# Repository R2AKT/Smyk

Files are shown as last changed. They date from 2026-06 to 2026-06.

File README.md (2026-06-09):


License addendum - https://github.com/R2AKT/Smyk/blob/main/Addendum.txt

# Smyk
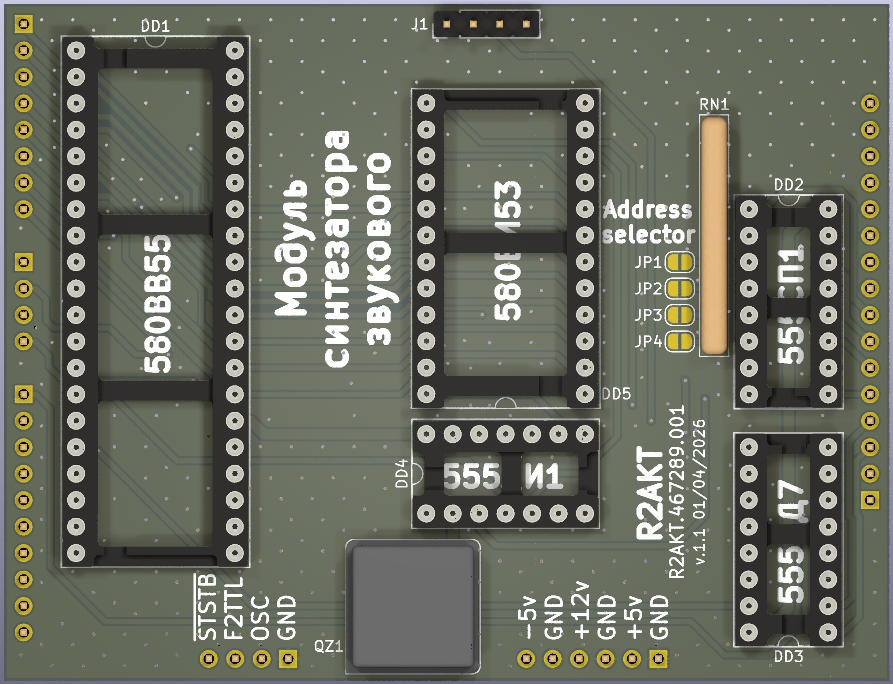
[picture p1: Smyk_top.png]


Sound synthesizer module (Smyk). For Mega-80 (Mega-580) DIY 8-bit micro-computer - https://github.com/R2AKT/Mega-80.

Generation of 3-channel 1-bit sound.

Based on 580VI53 (8253).

Status: In the process of testing.

Модуль синтезатора звукового (Smyk). Для самодельной 8-битной микро-ЭВМ - https://github.com/R2AKT/Mega-80.

Генерация 3-х канального 1-битного звука.

На основе 580ВИ53 (8253).

Статус: В процессе тестирования.

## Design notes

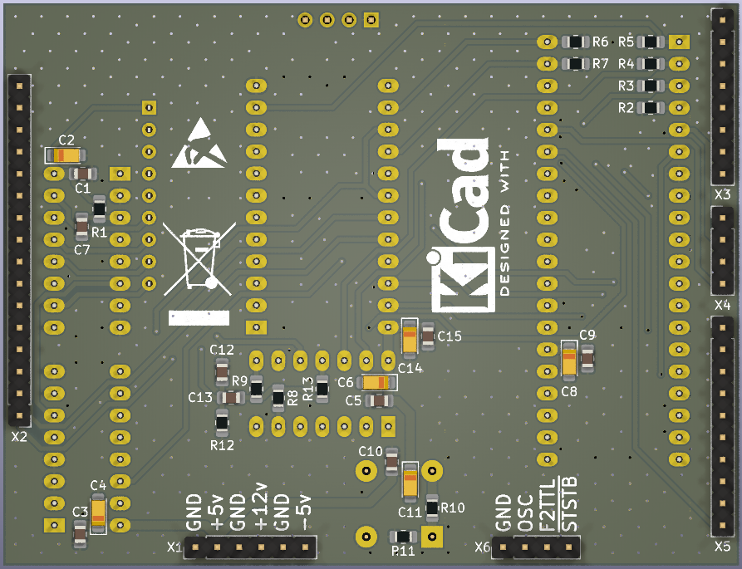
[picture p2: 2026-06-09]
Smyk_btn.png

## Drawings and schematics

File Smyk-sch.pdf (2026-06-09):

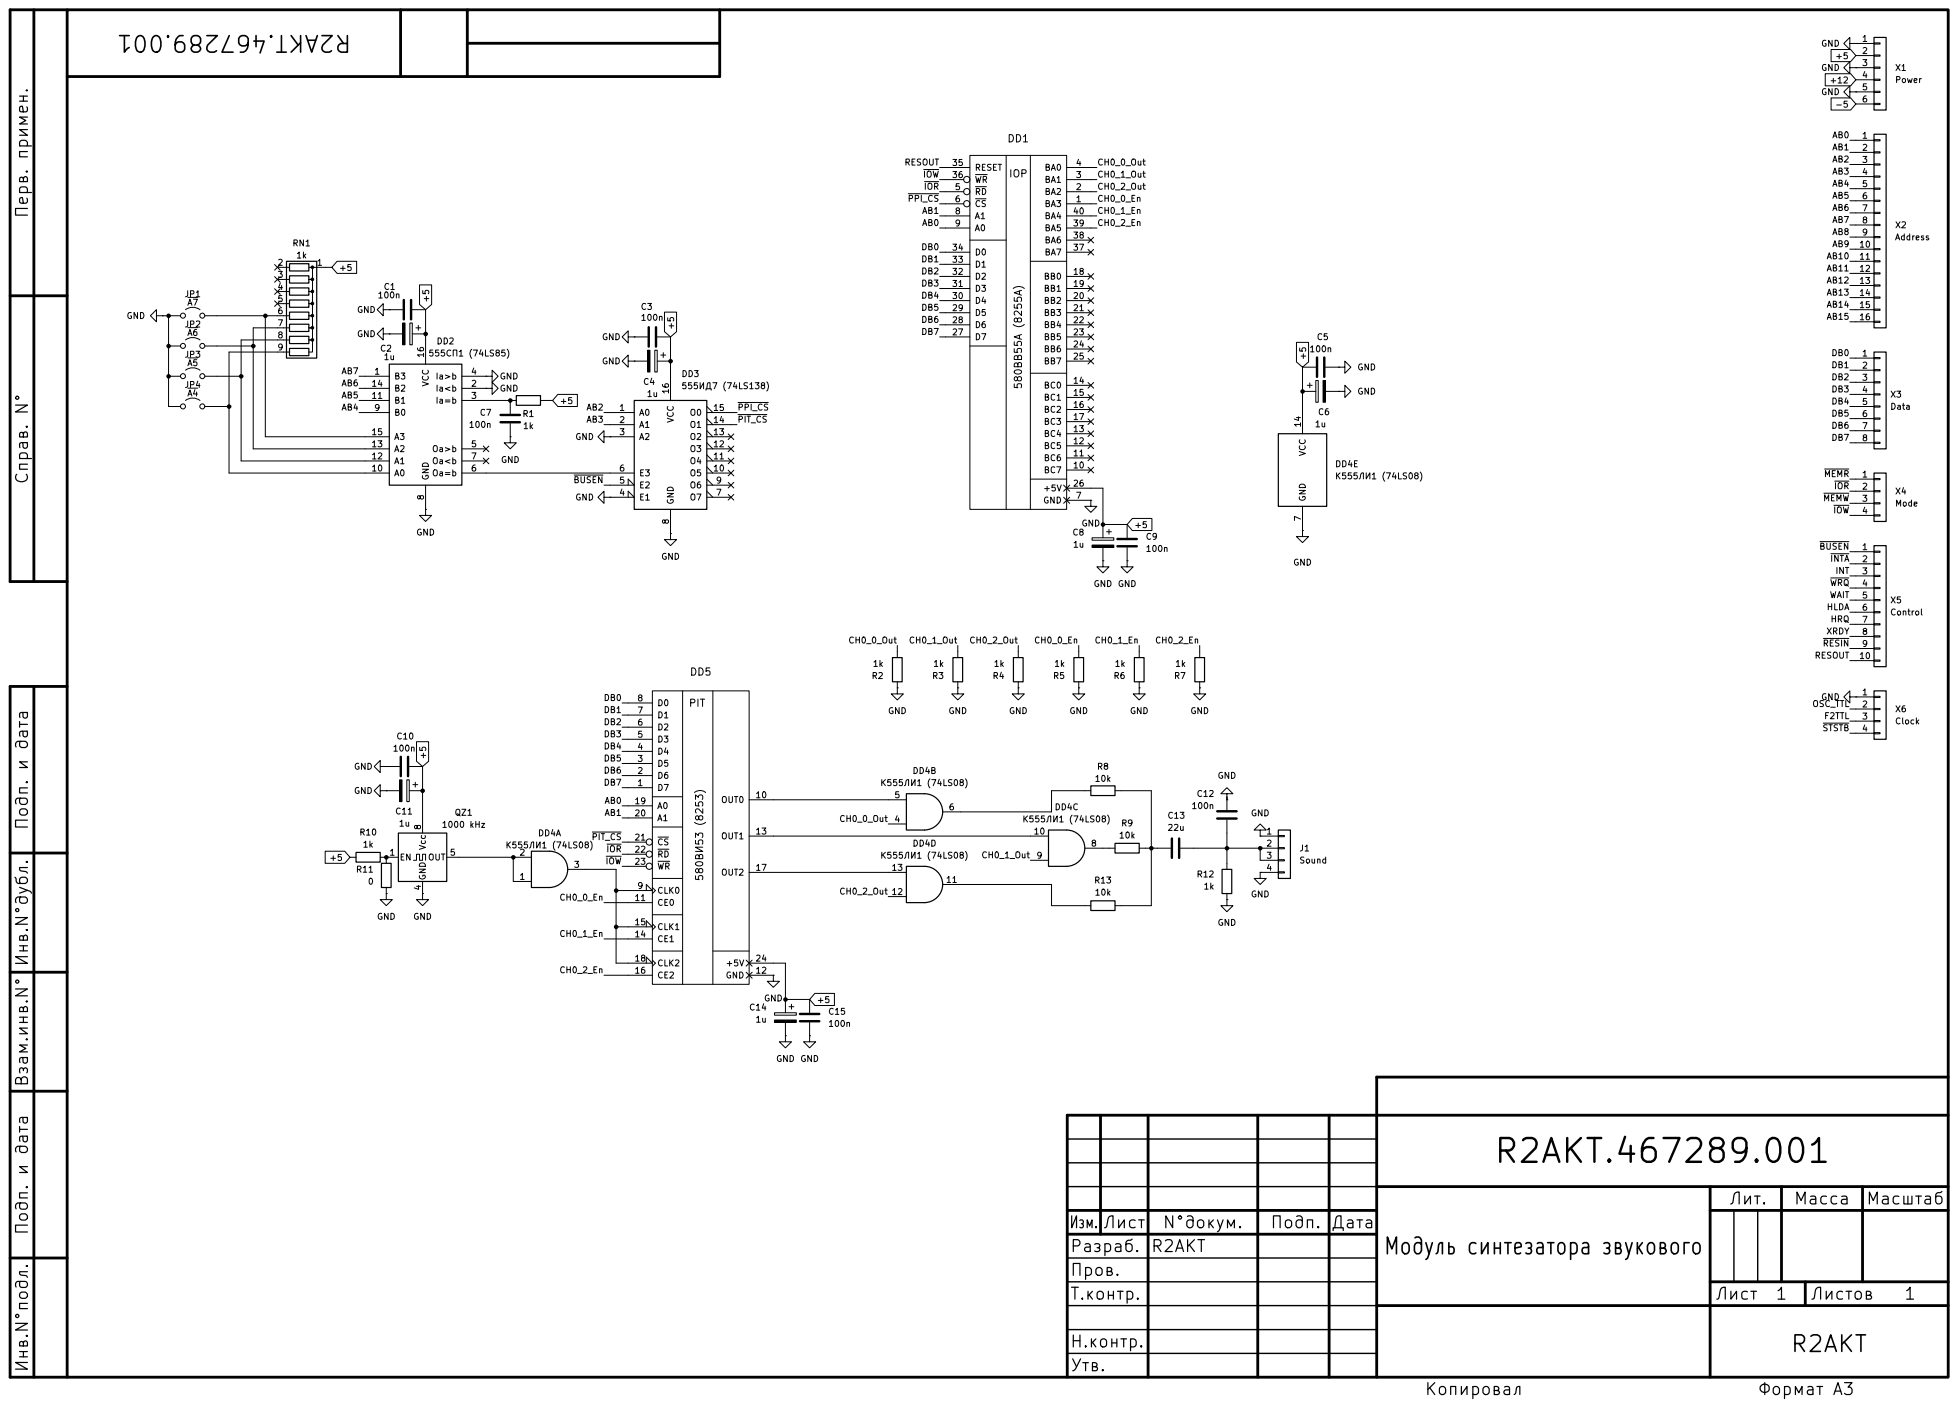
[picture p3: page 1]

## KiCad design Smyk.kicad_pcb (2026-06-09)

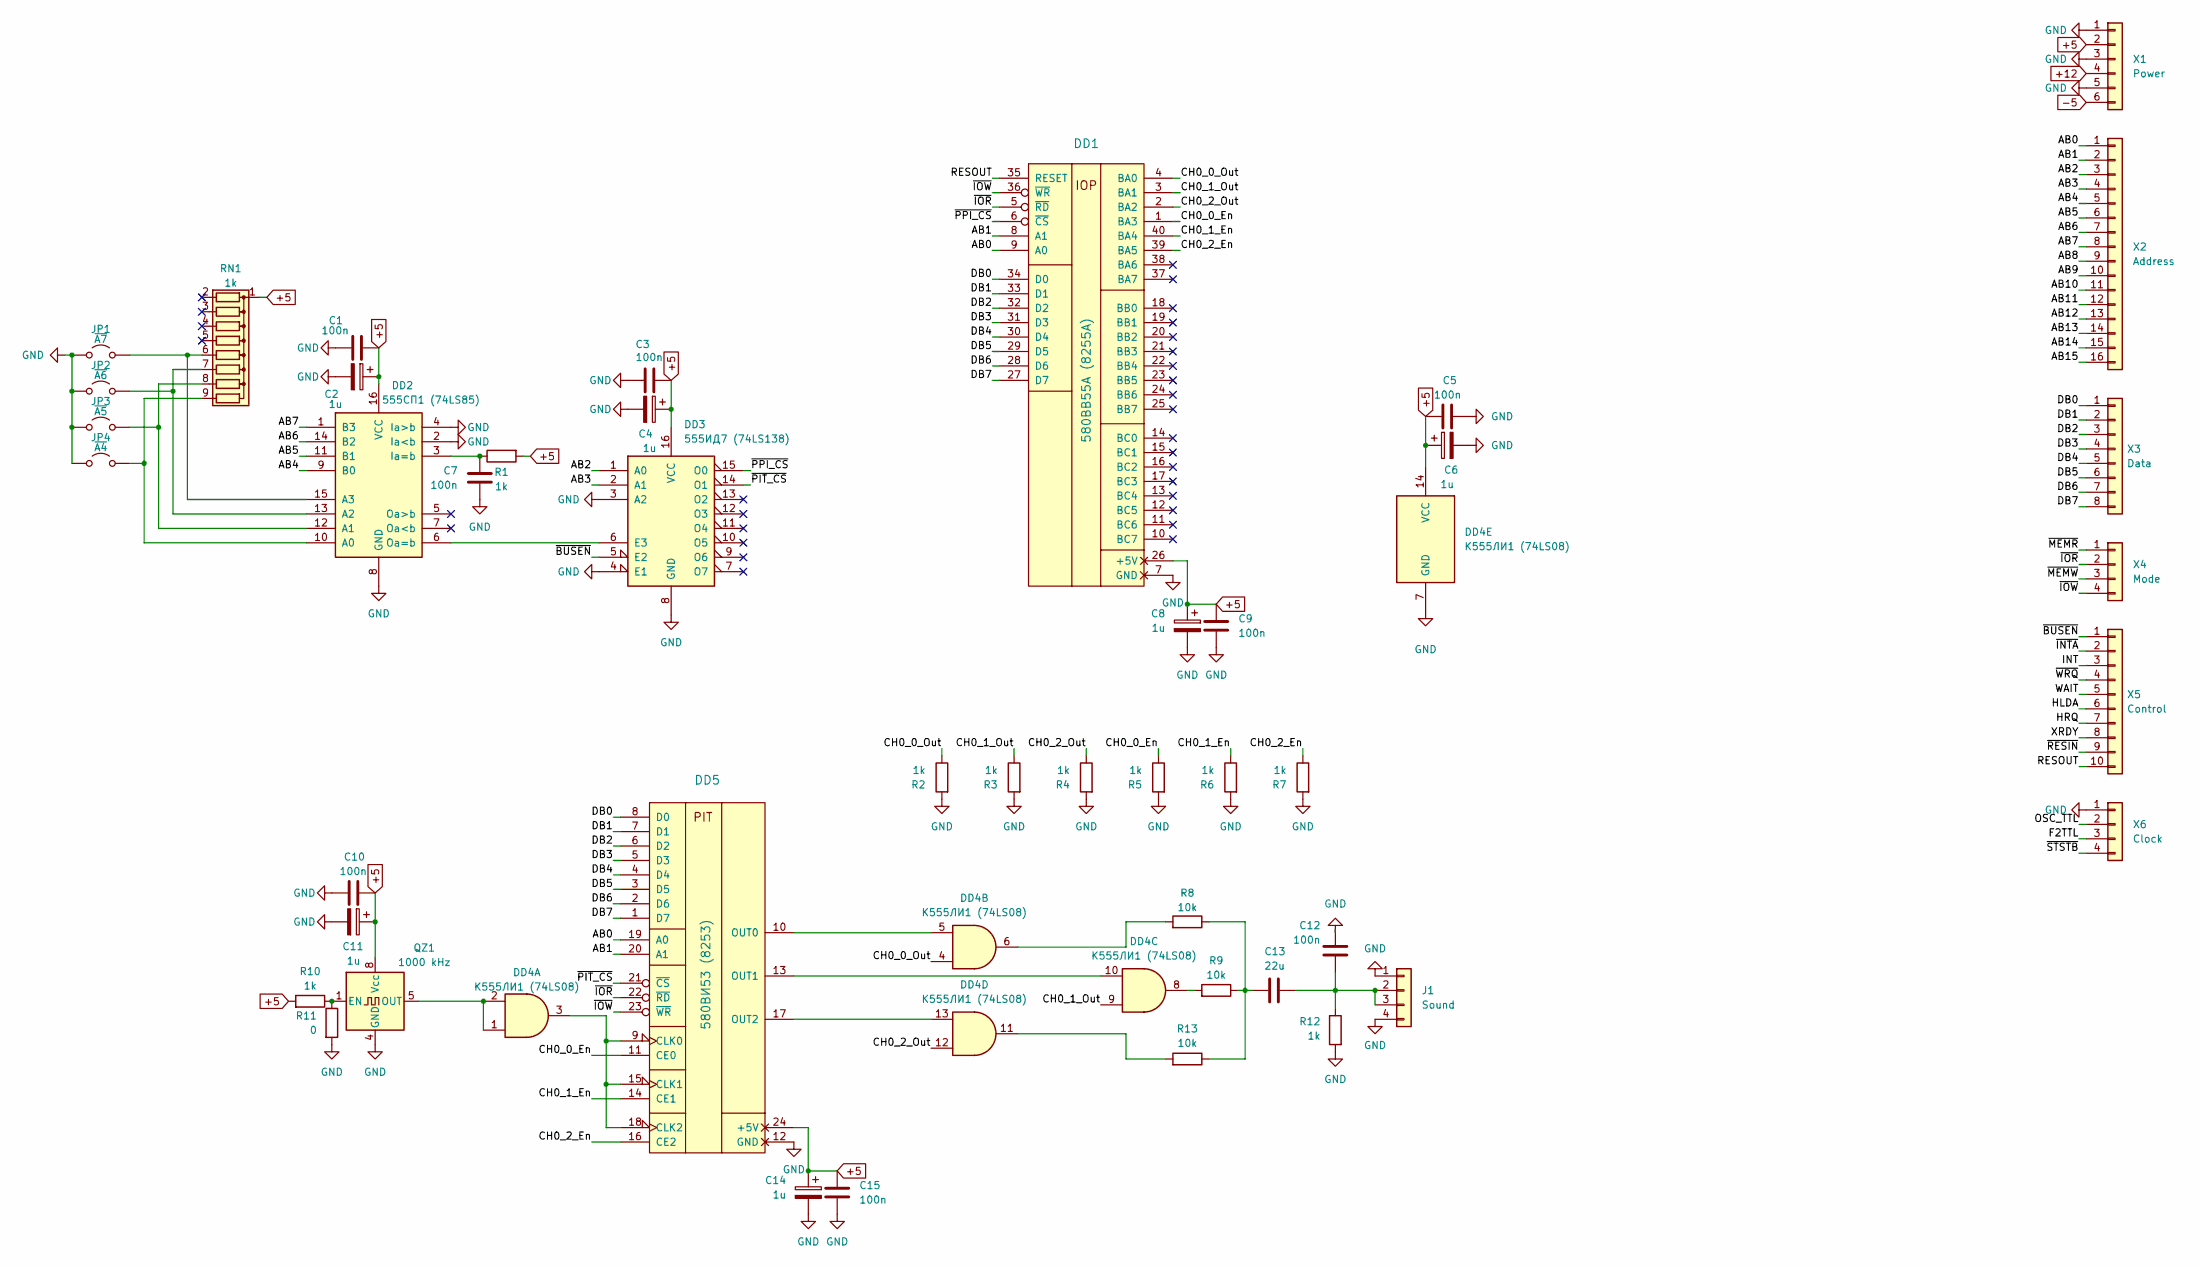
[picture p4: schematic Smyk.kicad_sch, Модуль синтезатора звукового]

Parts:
C1, C3, C5, C7, C9, C10, C12, C15: 100n; C_0805_2012Metric_Pad1.18x1.45mm_HandSolder
C2, C4, C6, C8, C11, C14: 1u; CP_EIA-3216-18_Kemet-A_Pad1.58x1.35mm_HandSolder
C13: 22u; C_0805_2012Metric_Pad1.18x1.45mm_HandSolder
DD1: 580ВВ55A (8255A); DIP-40_W15.24mm_Socket_LongPads
DD2: 555СП1 (74LS85); DIP-16_W7.62mm_Socket_LongPads
DD3: 555ИД7 (74LS138); DIP-16_W7.62mm_Socket_LongPads
DD4: К555ЛИ1 (74LS08); DIP-14_W7.62mm_Socket_LongPads
DD5: 580ВИ53 (8253); DIP-24_W15.24mm_Socket_LongPads
J1: Sound; PinHeader_1x04_P2.54mm_Vertical
JP1: ~{A7}; SolderJumper-2_P1.3mm_Open_RoundedPad1.0x1.5mm
JP2: ~{A6}; SolderJumper-2_P1.3mm_Open_RoundedPad1.0x1.5mm
JP3: ~{A5}; SolderJumper-2_P1.3mm_Open_RoundedPad1.0x1.5mm
JP4: ~{A4}; SolderJumper-2_P1.3mm_Open_RoundedPad1.0x1.5mm
QZ1: 1000 kHz; Oscillator_DIP-8_LargePads
R1, R2, R3, R4, R5, R6, R7, R10, R12: 1k; R_0805_2012Metric_Pad1.20x1.40mm_HandSolder
R8, R9, R13: 10k; R_0805_2012Metric_Pad1.20x1.40mm_HandSolder
R11: 0; R_0805_2012Metric_Pad1.20x1.40mm_HandSolder
RN1: 1k; R_Array_SIP9
X1: Power; PinHeader_1x06_P2.54mm_Vertical
X2: Address; PinHeader_1x16_P2.54mm_Vertical
X3: Data; PinHeader_1x08_P2.54mm_Vertical
X4: Mode; PinHeader_1x04_P2.54mm_Vertical
X5: Control; PinHeader_1x10_P2.54mm_Vertical
X6: Clock; PinHeader_1x04_P2.54mm_Vertical

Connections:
+5: C1.1, C2.1, C3.1, C4.1, C5.1, C6.1, C8.1, C9.1, C10.1, C11.1, C14.1, C15.1, DD1.26 (+5V), DD2.16 (VCC), DD3.16 (VCC), DD4.14 (VCC), DD5.24 (+5V), QZ1.8 (Vcc), R1.2, R10.2, RN1.1 (common), X1.2
+12: X1.4
-5: X1.6
/AB0: DD1.9 (A0), DD5.19 (A0), X2.1
/AB1: DD1.8 (A1), DD5.20 (A1), X2.2
/AB2: DD3.1 (A0), X2.3
/AB3: DD3.2 (A1), X2.4
/AB4: DD2.9 (B0), X2.5
/AB5: DD2.11 (B1), X2.6
/AB6: DD2.14 (B2), X2.7
/AB7: DD2.1 (B3), X2.8
/AB8: X2.9
/AB9: X2.10
/AB10: X2.11
/AB11: X2.12
/AB12: X2.13
/AB13: X2.14
/AB14: X2.15
/AB15: X2.16
/CH0_0_En: DD1.1 (BA3), DD5.11 (CE0), R5.1
/CH0_0_Out: DD1.4 (BA0), DD4.4, R2.1
/CH0_1_En: DD1.40 (BA4), DD5.14 (CE1), R6.1
/CH0_1_Out: DD1.3 (BA1), DD4.9, R3.1
/CH0_2_En: DD1.39 (BA5), DD5.16 (CE2), R7.1
/CH0_2_Out: DD1.2 (BA2), DD4.12, R4.1
/DB0: DD1.34 (D0), DD5.8 (D0), X3.1
/DB1: DD1.33 (D1), DD5.7 (D1), X3.2
/DB2: DD1.32 (D2), DD5.6 (D2), X3.3
/DB3: DD1.31 (D3), DD5.5 (D3), X3.4
/DB4: DD1.30 (D4), DD5.4 (D4), X3.5
/DB5: DD1.29 (D5), DD5.3 (D5), X3.6
/DB6: DD1.28 (D6), DD5.2 (D6), X3.7
/DB7: DD1.27 (D7), DD5.1 (D7), X3.8
/F2TTL: X6.3
/HLDA: X5.6
/HRQ: X5.7
/INT: X5.3
/OSC_TTL: X6.2
/RESOUT: DD1.35 (RESET), X5.10
/WAIT: X5.5
/XRDY: X5.8
/~BUSEN: DD3.5 (E2), X5.1
/~INTA: X5.2
/~IOR: DD1.5 (~RD), DD5.22 (~RD), X4.2
/~IOW: DD1.36 (~WR), DD5.23 (~WR), X4.4
/~MEMR: X4.1
/~MEMW: X4.3
/~PIT_CS: DD3.14 (O1), DD5.21 (~CS)
/~PPI_CS: DD1.6 (~CS), DD3.15 (O0)
/~RESIN: X5.9
/~STSTB: X6.4
/~WRQ: X5.4
GND: C1.2, C2.2, C3.2, C4.2, C5.2, C6.2, C7.2, C8.2, C9.2, C10.2, C11.2, C12.1, C14.2, C15.2, DD1.7 (GND), DD2.2 (Ia<b), DD2.4 (Ia>b), DD2.8 (GND), DD3.3 (A2), DD3.4 (E1), DD3.8 (GND), DD4.7 (GND), DD5.12 (GND), J1.1, J1.4, JP1.1 (A), JP2.1 (A), JP3.1 (A), JP4.1 (A), QZ1.4 (GND), R2.2, R3.2, R4.2, R5.2, R6.2, R7.2, R11.2, R12.2, X1.1, X1.3, X1.5, X6.1
unnamed: C13.2, R8.1, R9.1, R13.1
unnamed: DD2.10 (A0), JP4.2 (B), RN1.9 (R8)
unnamed: DD2.12 (A1), JP3.2 (B), RN1.8 (R7)
unnamed: DD2.13 (A2), JP2.2 (B), RN1.7 (R6)
unnamed: DD2.15 (A3), JP1.2 (B), RN1.6 (R5)
unnamed: C7.1, DD2.3 (Ia=b), R1.1
unnamed: DD2.6 (Oa=b), DD3.6 (E3)
unnamed: DD4.6, R8.2
unnamed: DD4.8, R9.2
unnamed: DD4.11, R13.2
unnamed: DD4.3, DD5.9 (CLK0), DD5.15 (CLK1), DD5.18 (CLK2)
unnamed: DD4.5, DD5.10 (OUT0)
unnamed: DD4.10, DD5.13 (OUT1)
unnamed: DD4.13, DD5.17 (OUT2)
unnamed: C12.2, C13.1, J1.2, J1.3, R12.1
unnamed: QZ1.1 (EN), R10.1, R11.1
unnamed: DD4.1, DD4.2, QZ1.5 (OUT)

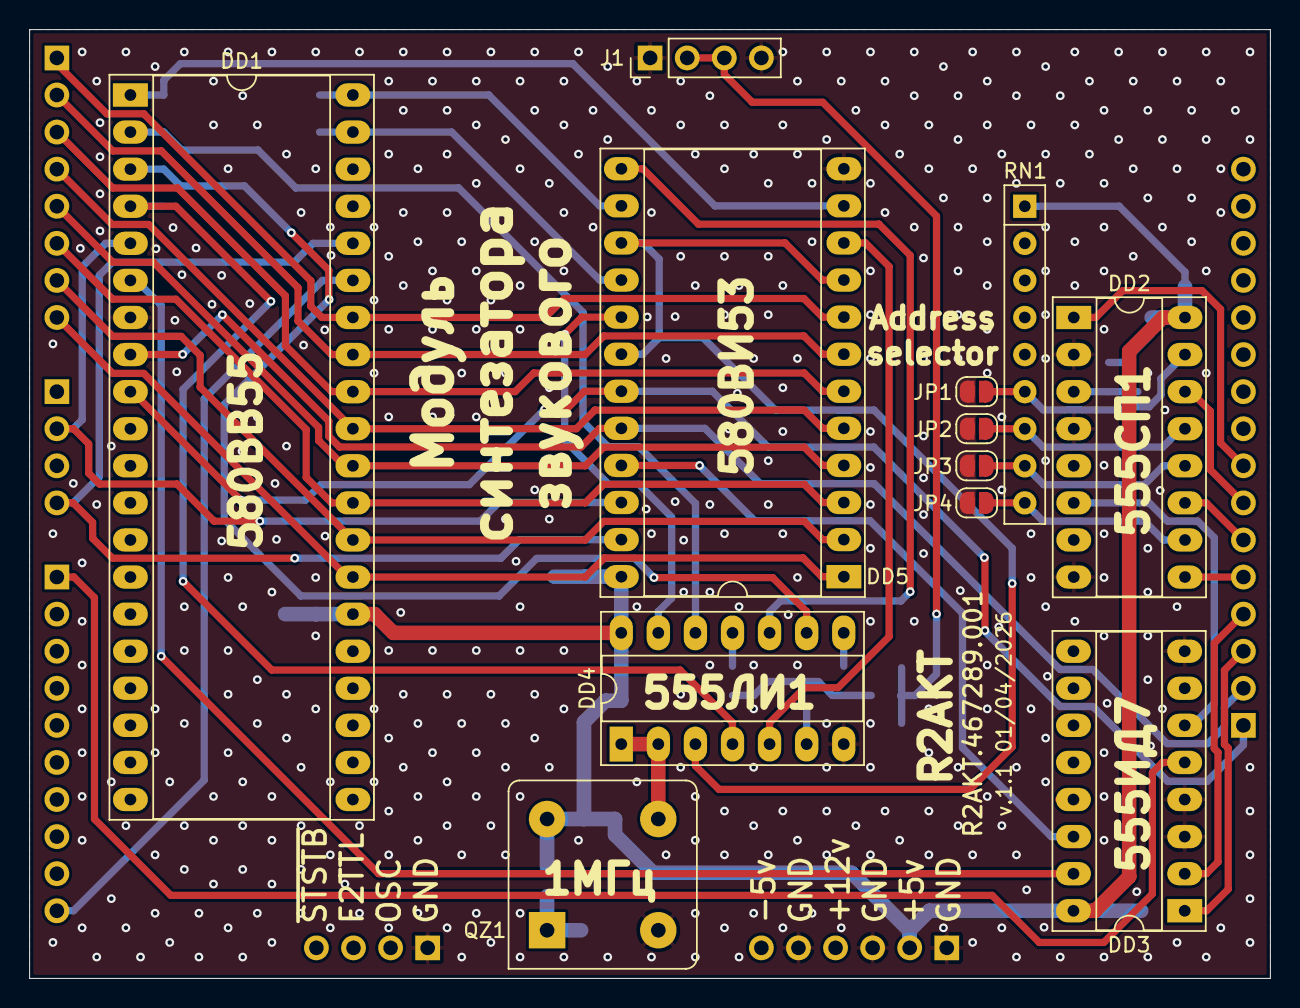
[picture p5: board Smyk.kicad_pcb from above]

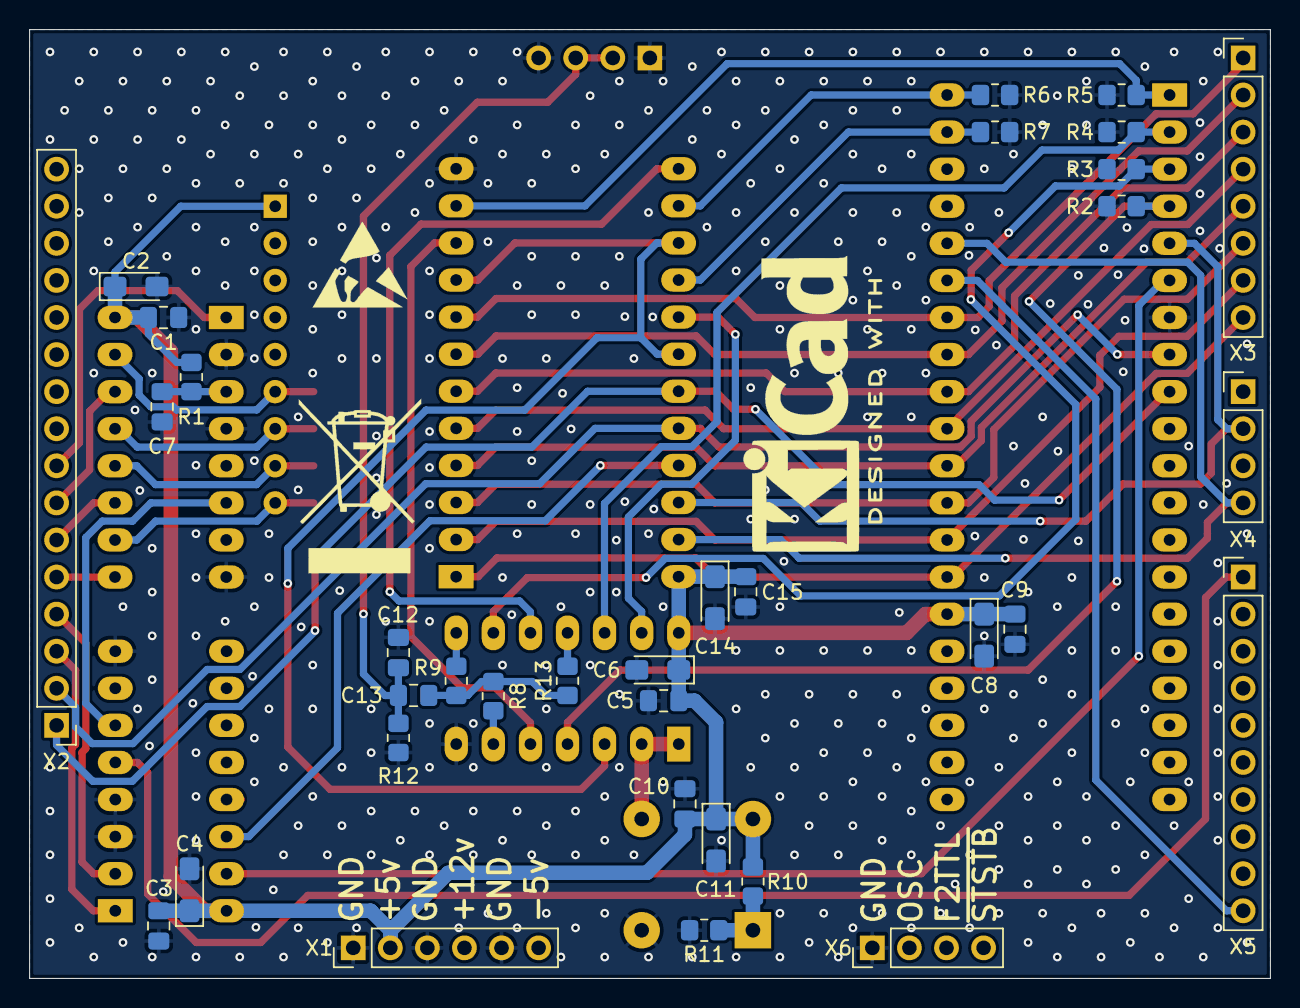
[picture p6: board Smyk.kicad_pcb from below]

Board: 2 copper layers, 85.0 x 65.0 mm, 46 parts (34 on the bottom side), 47 nets.

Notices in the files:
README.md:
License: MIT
